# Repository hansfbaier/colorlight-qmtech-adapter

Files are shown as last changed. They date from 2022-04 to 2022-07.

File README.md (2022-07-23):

# colorlight-qmtech-adapter
Adapter to use Colorlight i5/i9 FPGA boards in a QMTech board form factor



Please note:
* J1 Pin 8 is not length matched to the other Pins.
* J1 Pins 59 and 60 are not connected!

# Variants
* [With vertical connector] (https://github.com/hansfbaier/colorlight-qmtech-adapter/tree/upright-connector)
* [With vertical connector and ethernet jacks] (https://github.com/hansfbaier/colorlight-qmtech-adapter/tree/upright-with-ethernet)
* [With horizontal connector and ethernet jacks] (https://github.com/hansfbaier/colorlight-qmtech-adapter/tree/horizontal-with-ethernet)

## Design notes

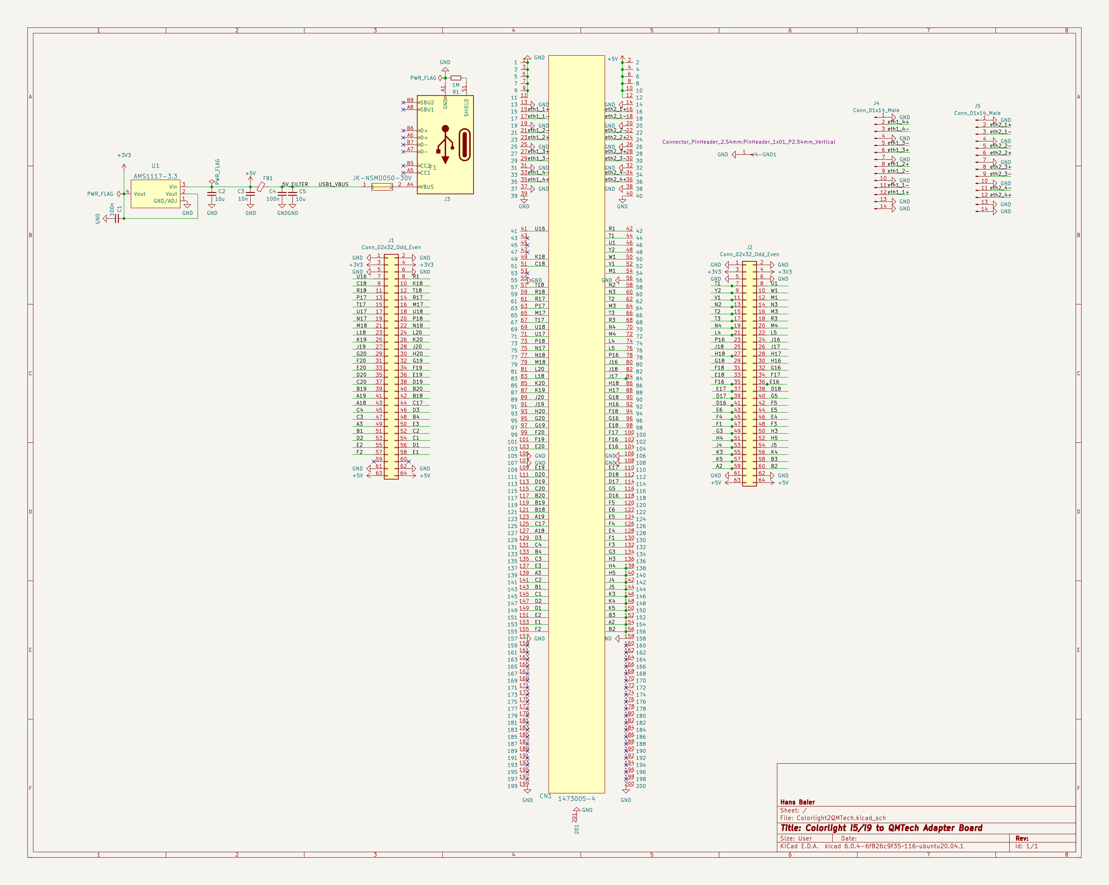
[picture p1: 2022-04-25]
schematic.png

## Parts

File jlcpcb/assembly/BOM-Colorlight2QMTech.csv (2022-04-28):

Comment | Designator | Footprint | LCSC
100n | C1,C4 | C_0603_1608Metric | C14663
10u | C2,C5 | C_0805_2012Metric | C15850
Connector_USB_C_Receptacle_USB2.0 | J3 | USB-C_SMD-TYPE-C-31-M-12 | C165948
10n | C3 | C_0805_2012Metric | C1710
1M | R1 | R_0603_1608Metric | C22935
1473005-4 | CN1 | SO-DIMM-SMD_200P-P0.60_1473005-4 | C428482
AMS1117-3.3 | U1 | SOT-223-3_L6.5-W3.4-P2.30-LS7.0-BR | C6186
JK-NSMD050-30V | F1 | F1206 | C720075
2A | FB1 | L_1206_3216Metric | C73732
Conn_02x32_Odd_Even | J1 | PinHeader_2x32_P2.54mm_Vertical
Conn_02x32_Odd_Even | J2 | PinHeader_2x32_P2.54mm_Vertical
Conn_01x01_Male | J4-GND1 | PinHeader_1x01_P2.54mm_Vertical
Conn_01x14_Male | J4 | PinHeader_1x14_P1.00mm_Vertical
Conn_01x14_Male | J5 | PinHeader_1x14_P1.00mm_Vertical

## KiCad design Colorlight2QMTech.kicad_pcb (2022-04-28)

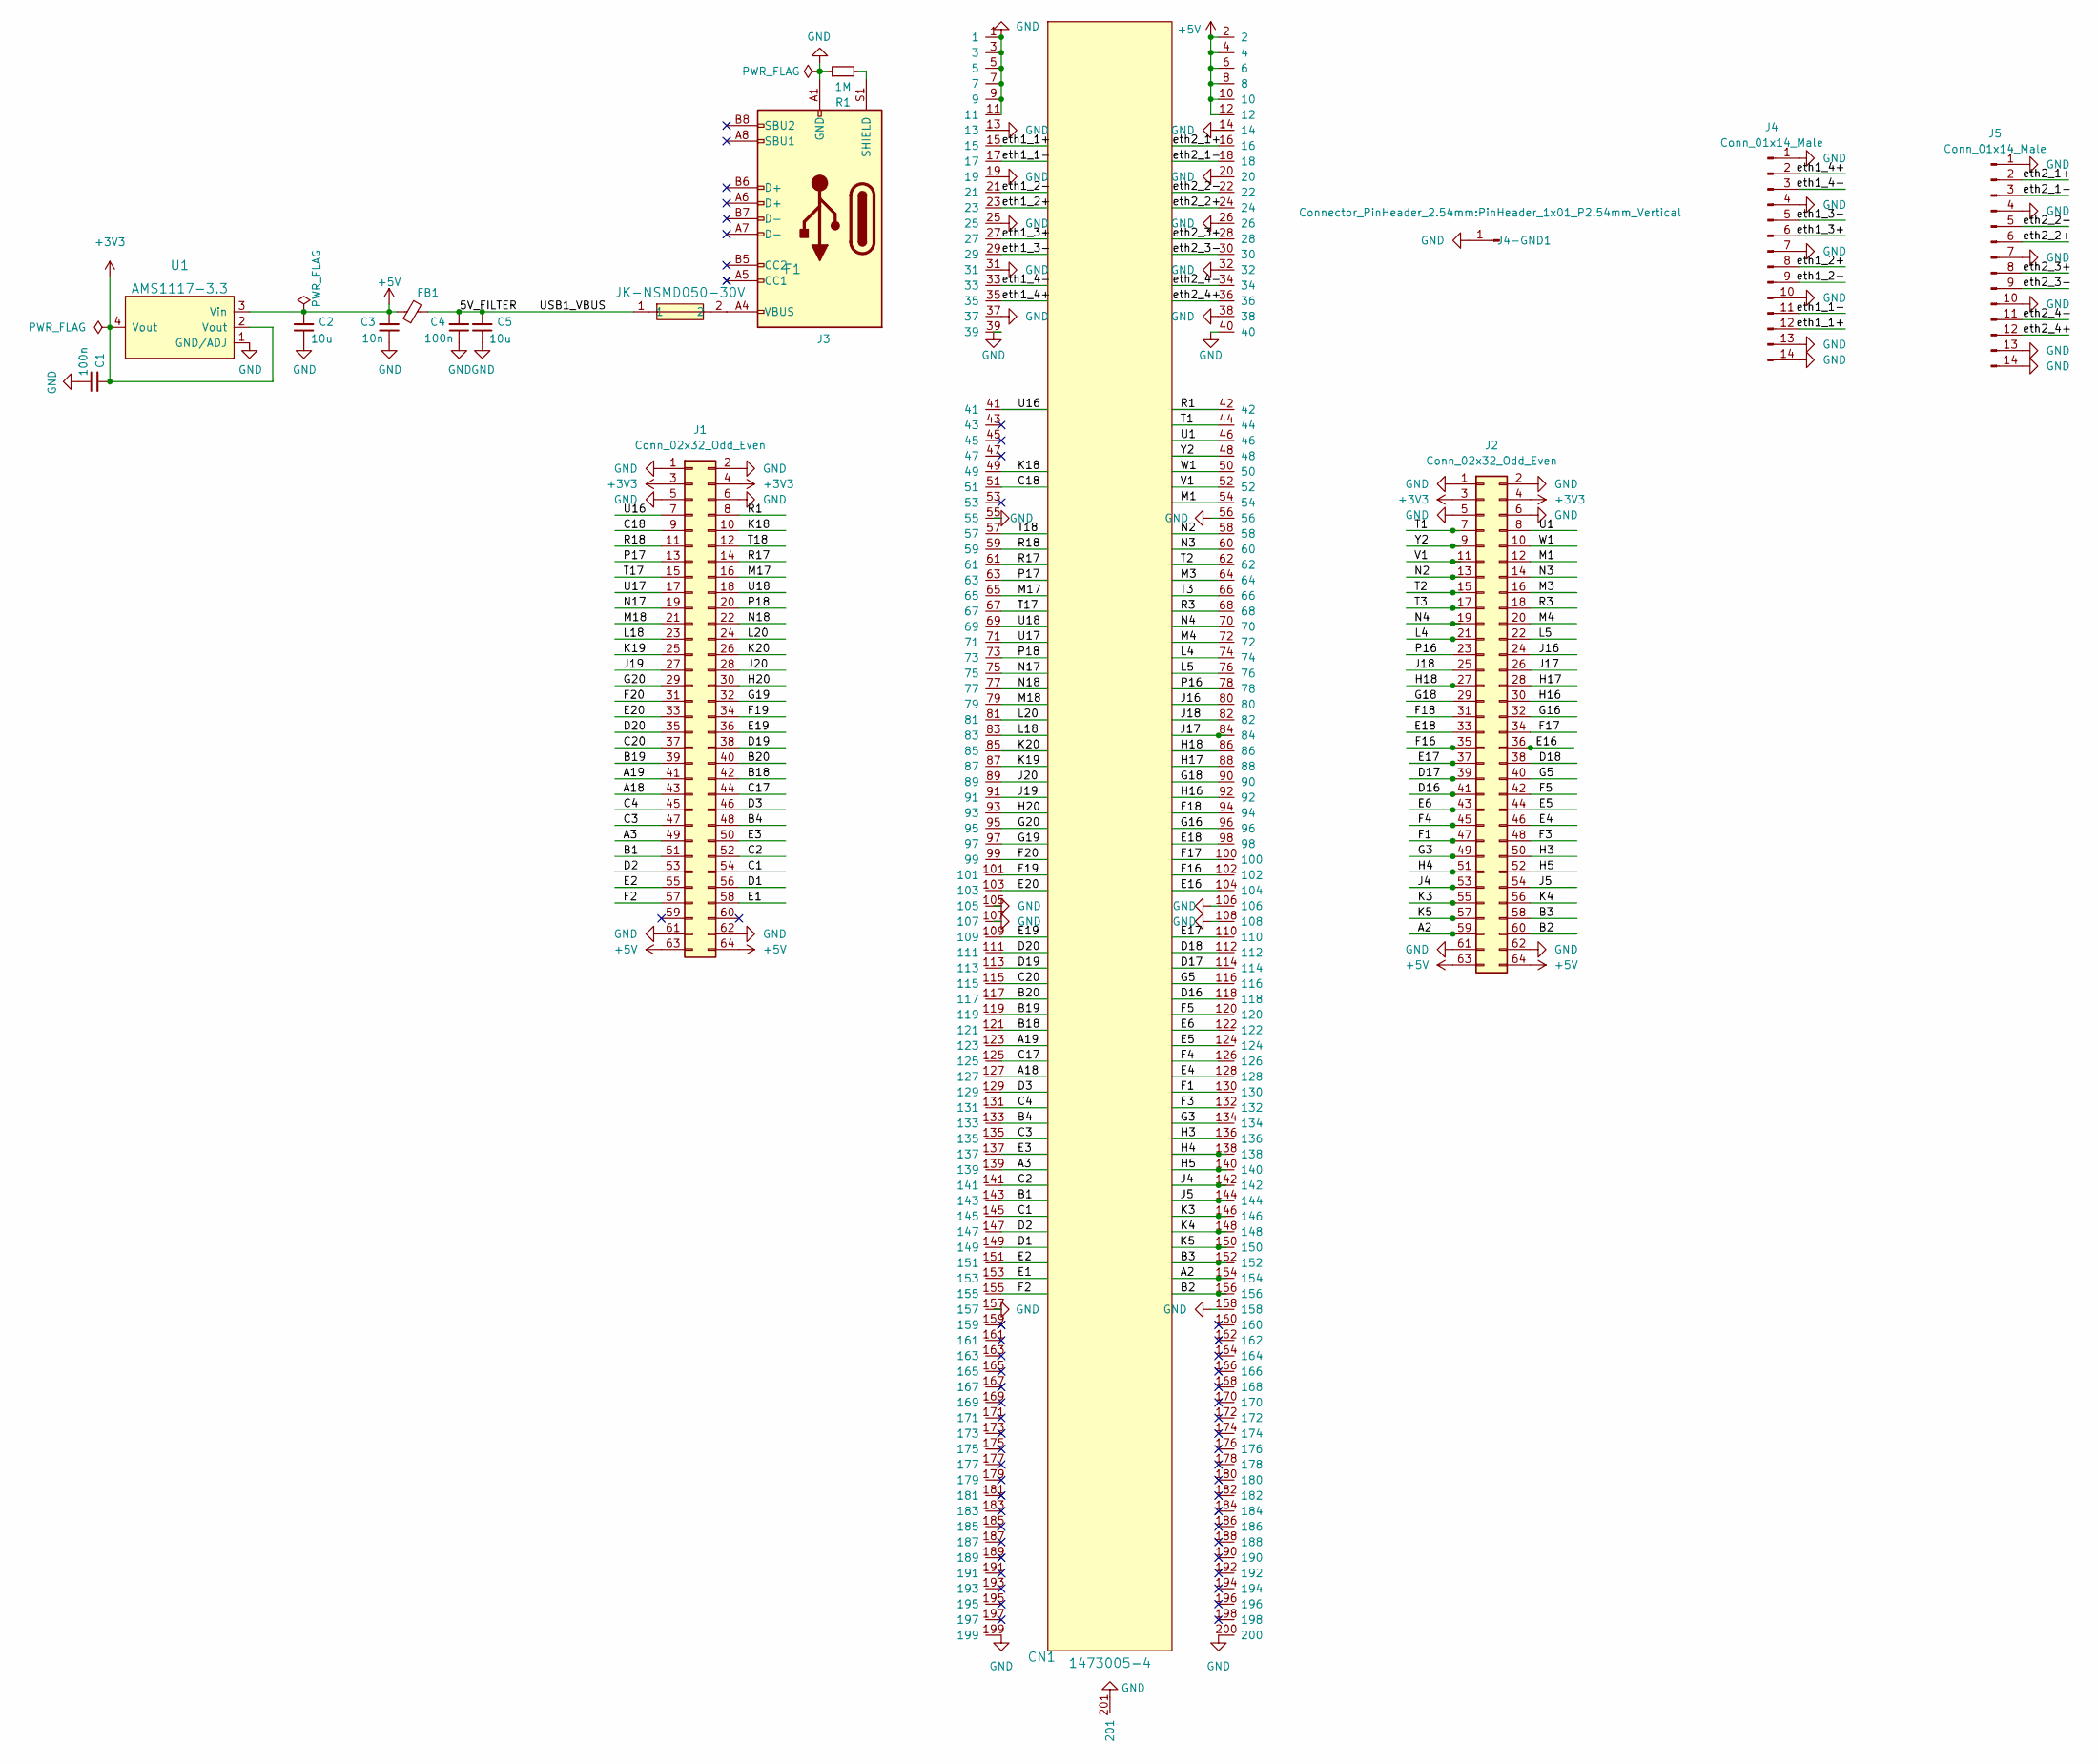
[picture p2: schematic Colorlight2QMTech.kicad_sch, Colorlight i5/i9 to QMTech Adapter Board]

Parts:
C1, C4: 100n; C_0603_1608Metric; LCSC C14663
C2, C5: 10u; C_0805_2012Metric; LCSC C15850
C3: 10n; C_0805_2012Metric; LCSC C1710
CN1: 1473005-4; SO-DIMM-SMD_200P-P0.60_1473005-4; LCSC Part C428482
F1: JK-NSMD050-30V; F1206; LCSC Part C720075
FB1: 2A; L_1206_3216Metric; LCSC C73732
J1, J2: Conn_02x32_Odd_Even; PinHeader_2x32_P2.54mm_Vertical
J3: Connector_USB_C_Receptacle_USB2.0; USB-C_SMD-TYPE-C-31-M-12; LCSC C165948
J4, J5: Conn_01x14_Male
J4-GND1: Conn_01x01_Male; PinHeader_1x01_P2.54mm_Vertical
R1: 1M; R_0603_1608Metric; LCSC C22935
U1: AMS1117-3.3; SOT-223-3_L6.5-W3.4-P2.30-LS7.0-BR; LCSC Part C6186

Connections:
+3V3: C1.2, J1.3, J1.4, J2.3, J2.4, U1.2 (Vout), U1.4 (Vout)
+5V: C2.2, C3.2, CN1.2, CN1.4, CN1.6, CN1.8, CN1.10, CN1.12, FB1.1, J1.63, J1.64, J2.63, J2.64, U1.3 (Vin)
/5V_FILTER: C4.2, C5.2, F1.1, FB1.2
/A2: CN1.154, J2.59
/A3: CN1.139, J1.49
/A18: CN1.127, J1.43
/A19: CN1.123, J1.41
/B1: CN1.143, J1.51
/B2: CN1.156, J2.60
/B3: CN1.152, J2.58
/B4: CN1.133, J1.48
/B18: CN1.121, J1.42
/B19: CN1.119, J1.39
/B20: CN1.117, J1.40
/C1: CN1.145, J1.54
/C2: CN1.141, J1.52
/C3: CN1.135, J1.47
/C4: CN1.131, J1.45
/C17: CN1.125, J1.44
/C18: CN1.51, J1.9
/C20: CN1.115, J1.37
/D1: CN1.149, J1.56
/D2: CN1.147, J1.53
/D3: CN1.129, J1.46
/D16: CN1.118, J2.41
/D17: CN1.114, J2.39
/D18: CN1.112, J2.38
/D19: CN1.113, J1.38
/D20: CN1.111, J1.35
/E1: CN1.153, J1.58
/E2: CN1.151, J1.55
/E3: CN1.137, J1.50
/E4: CN1.128, J2.46
/E5: CN1.124, J2.44
/E6: CN1.122, J2.43
/E16: CN1.104, J2.36
/E17: CN1.110, J2.37
/E18: CN1.98, J2.33
/E19: CN1.109, J1.36
/E20: CN1.103, J1.33
/F1: CN1.130, J2.47
/F2: CN1.155, J1.57
/F3: CN1.132, J2.48
/F4: CN1.126, J2.45
/F5: CN1.120, J2.42
/F16: CN1.102, J2.35
/F17: CN1.100, J2.34
/F18: CN1.94, J2.31
/F19: CN1.101, J1.34
/F20: CN1.99, J1.31
/G3: CN1.134, J2.49
/G5: CN1.116, J2.40
/G16: CN1.96, J2.32
/G18: CN1.90, J2.29
/G19: CN1.97, J1.32
/G20: CN1.95, J1.29
/H3: CN1.136, J2.50
/H4: CN1.138, J2.51
/H5: CN1.140, J2.52
/H16: CN1.92, J2.30
/H17: CN1.88, J2.28
/H18: CN1.86, J2.27
/H20: CN1.93, J1.30
/J4: CN1.142, J2.53
/J5: CN1.144, J2.54
/J16: CN1.80, J2.24
/J17: CN1.84, J2.26
/J18: CN1.82, J2.25
/J19: CN1.91, J1.27
/J20: CN1.89, J1.28
/K3: CN1.146, J2.55
/K4: CN1.148, J2.56
/K5: CN1.150, J2.57
/K18: CN1.49, J1.10
/K19: CN1.87, J1.25
/K20: CN1.85, J1.26
/L4: CN1.74, J2.21
/L5: CN1.76, J2.22
/L18: CN1.83, J1.23
/L20: CN1.81, J1.24
/M1: CN1.54, J2.12
/M3: CN1.64, J2.16
/M4: CN1.72, J2.20
/M17: CN1.65, J1.16
/M18: CN1.79, J1.21
/N2: CN1.58, J2.13
/N3: CN1.60, J2.14
/N4: CN1.70, J2.19
/N17: CN1.75, J1.19
/N18: CN1.77, J1.22
/P16: CN1.78, J2.23
/P17: CN1.63, J1.13
/P18: CN1.73, J1.20
/R1: CN1.42, J1.8
/R3: CN1.68, J2.18
/R17: CN1.61, J1.14
/R18: CN1.59, J1.11
/T1: CN1.44, J2.7
/T2: CN1.62, J2.15
/T3: CN1.66, J2.17
/T17: CN1.67, J1.15
/T18: CN1.57, J1.12
/U1: CN1.46, J2.8
/U16: CN1.41, J1.7
/U17: CN1.71, J1.17
/U18: CN1.69, J1.18
/V1: CN1.52, J2.11
/W1: CN1.50, J2.10
/Y2: CN1.48, J2.9
/eth1_1+: CN1.15, J4.12
/eth1_1-: CN1.17, J4.11
/eth1_2+: CN1.23, J4.8
/eth1_2-: CN1.21, J4.9
/eth1_3+: CN1.27, J4.6
/eth1_3-: CN1.29, J4.5
/eth1_4+: CN1.35, J4.2
/eth1_4-: CN1.33, J4.3
/eth2_1+: CN1.16, J5.2
/eth2_1-: CN1.18, J5.3
/eth2_2+: CN1.24, J5.6
/eth2_2-: CN1.22, J5.5
/eth2_3+: CN1.28, J5.8
/eth2_3-: CN1.30, J5.9
/eth2_4+: CN1.36, J5.12
/eth2_4-: CN1.34, J5.11
GND: C1.1, C2.1, C3.1, C4.1, C5.1, CN1.1, CN1.3, CN1.5, CN1.7, CN1.9, CN1.11, CN1.13, CN1.14, CN1.19, CN1.20, CN1.25, CN1.26, CN1.31, CN1.32, CN1.37, CN1.38, CN1.39, CN1.40, CN1.55, CN1.56, CN1.105, CN1.106, CN1.107, CN1.108, CN1.157, CN1.158, CN1.199, CN1.200, CN1.201, J1.1, J1.2, J1.5, J1.6, J1.61, J1.62, J2.1, J2.2, J2.5, J2.6, J2.61, J2.62, J3.A1 (GND), J3.A12 (GND), J3.B1 (GND), J3.B12 (GND), J4.1, J4.4, J4.7, J4.10, J4.13, J4.14, J4-GND1.1, J5.1, J5.4, J5.7, J5.10, J5.13, J5.14, R1.1, U1.1 (GND/ADJ)
unnamed: F1.2, J3.A4 (VBUS), J3.A9 (VBUS), J3.B4 (VBUS), J3.B9 (VBUS)
unnamed: J3.S1 (SHIELD), R1.2

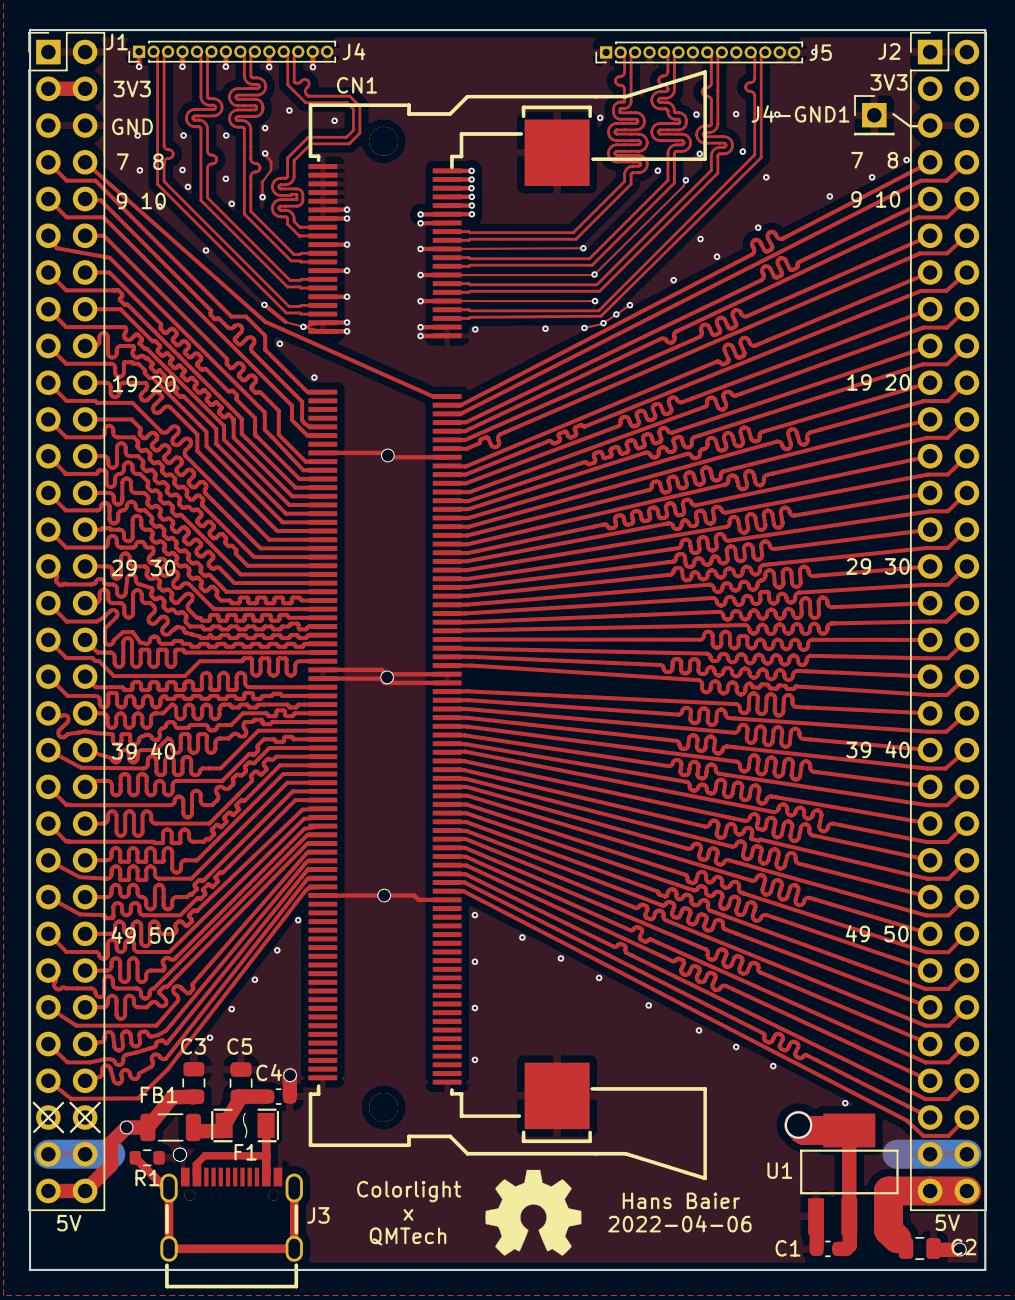
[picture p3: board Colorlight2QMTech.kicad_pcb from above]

Board: 4 copper layers, 66.0 x 85.7 mm, 17 parts (0 on the bottom side), 128 nets.

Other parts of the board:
N1: OHWLOGO; OSHW-Symbol_6.7x6mm_SilkScreen

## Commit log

2022-04-09 make headers face down in 3D view
    [Colorlight2QMTech.kicad_pcb]
2022-04-09 tidy schematic and export
    [Colorlight2QMTech.kicad_sch]
2022-04-25 New revision and first release: Fixed routing issues, better silk screen, break out ethernet signals.
    [BOM-Colorlight2QMTech.csv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]
2022-04-25 beautify schematic and export
    [Colorlight2QMTech.kicad_sch]
2022-04-28 fix DRC track spacing
    [BOM-Colorlight2QMTech.csv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]
2022-04-28 make track widths a bit smaller to satisfy .105mm spacing
    [BOM-Colorlight2QMTech.csv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]
